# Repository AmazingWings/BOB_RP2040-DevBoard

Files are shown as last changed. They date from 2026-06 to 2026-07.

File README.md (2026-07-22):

<div align="center">

# BOB
### A Raspberry Pi RP2040 development board




### [Key Features](#key-features) • [PCB](#pcb) • [Credits](#credits) • [License](#license)

</div>

---

## Welcome!
Hi! This is my first SMT board! It is a custom RP2040 development board named BOB. I chose BOB as the name because I like Bob; it's a fun name to say. But on the other hand, it is designed to act as a platform for me to learn SMT board design. The reason why I made it was not only to learn how to make a fully SMT board, but to serve as a platform for learning for my future flight computer designs I will do for my rockets. I wanted to transition away from using software like EasyEDA to more professional software like KiCad, which is much more widely used. Through this project, I not only learned SMT schematic design but also routing. In EasyEDA, I used to autoroute my components, but in KiCad and through this project, I learned how to route components and place components by myself, transitioning away from my dependencies with breakout boards. 

### Key features:
1. Dual-core processor with up to 133 MHz in speed.
2. 264 KB of on-chip SRAM.
3. Programmable through USB-C.
4. 30 GPIO pins that can run I2C, SPI, and UART. 
5. 2-layer PCB design: top layer for components and bottom layer for ground wiring and signal routing, along with the top layer for signal wiring and power wiring.

---

## PCB

### Schematic Design 
<p align="center">
  Schematic Design
</p>

### PCB Design
<p align="center">
  PCB Design
</p>

### 3D Design
<p align="center">
  3D Design
</p>

### JLC PCB 3D Design
<p align="center">
  JLC PCB 3D Design
</p>

### BOM
<p <p align="center">
  Screenshot 2026-07-22 at 1 04 08 PM
</p>

### Final Cost Estimate
<p align="center">
  Final Cost Estimate
</p>

---

## Credits
1. https://macondo.hackclub.com/docs/build-a-devboard
2. [KiCad](https://www.kicad.org/) 
3. [JLCPCB](https://jlcpcb.com/)

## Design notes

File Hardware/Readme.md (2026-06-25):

<div align="center">

# Production Files
### RP2040 BOB Devboard
</div>

---

This folder contains all the necessary production files required to manufacture the **RP2040 BOB devboard**. 

---

## 🛠️ How to Use (Manufacturing)

If you want to order this board, simply **drag and drop the entire folder into JLCPCB**. Their system will automatically detect and compile all the necessary files you need for production.

## 📄 Key Files

* **BOM (Bill of Materials):** Provided in standard `.csv` format, ready for component sourcing and assembly.

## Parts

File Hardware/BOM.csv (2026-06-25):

RP2040_dev
Id | Designator | Footprint | Quantity | Comment | Supplier and ref
1 | 33pF2, 33pF3 | C_0402_1005Metric | 2 | 33pF
2 | C1, C2, C3, C4, C5, C6, C7, C8, C9, C11, C12, C15 | C_0402_1005Metric | 12 | 0.1uF
3 | C10 | C_0402_1005Metric | 1 | 1uF
4 | C13, C14 | C_0603_1608Metric | 2 | 10uF
5 | J1 | USB_C_Receptacle_HRO_TYPE-C-31-M-12 | 1 | USB_C_Receptacle_USB2.0_14P
6 | J2, J4 | PinHeader_1x20_P2.54mm_Vertical | 2 | Conn_01x20
7 | J3 | PinHeader_1x03_P2.54mm_Vertical | 1 | Conn_01x03
8 | R1, R2 | R_0402_1005Metric | 2 | 5.1K
9 | R3, R4 | R_0402_1005Metric | 2 | 27
10 | R5, R6 | R_0402_1005Metric | 2 | 1K
11 | R7 | R_0402_1005Metric | 1 | 10K
12 | SW1 | SW_Push_SPST_NO_Alps_SKRK | 1 | SW_Push
13 | U1 | QFN-56-1EP_7x7mm_P0.4mm_EP3.2x3.2mm | 1 | RP2040
14 | U2 | SOT-23 | 1 | MCP1700x-330xxTT
15 | U4 | Winbond_USON-8-1EP_3x2mm_P0.5mm_EP0.2x1.6mm | 1 | W25Q16JVSS
16 | Y1 | Crystal_SMD_3225-4Pin_3.2x2.5mm | 1 | 12mhz

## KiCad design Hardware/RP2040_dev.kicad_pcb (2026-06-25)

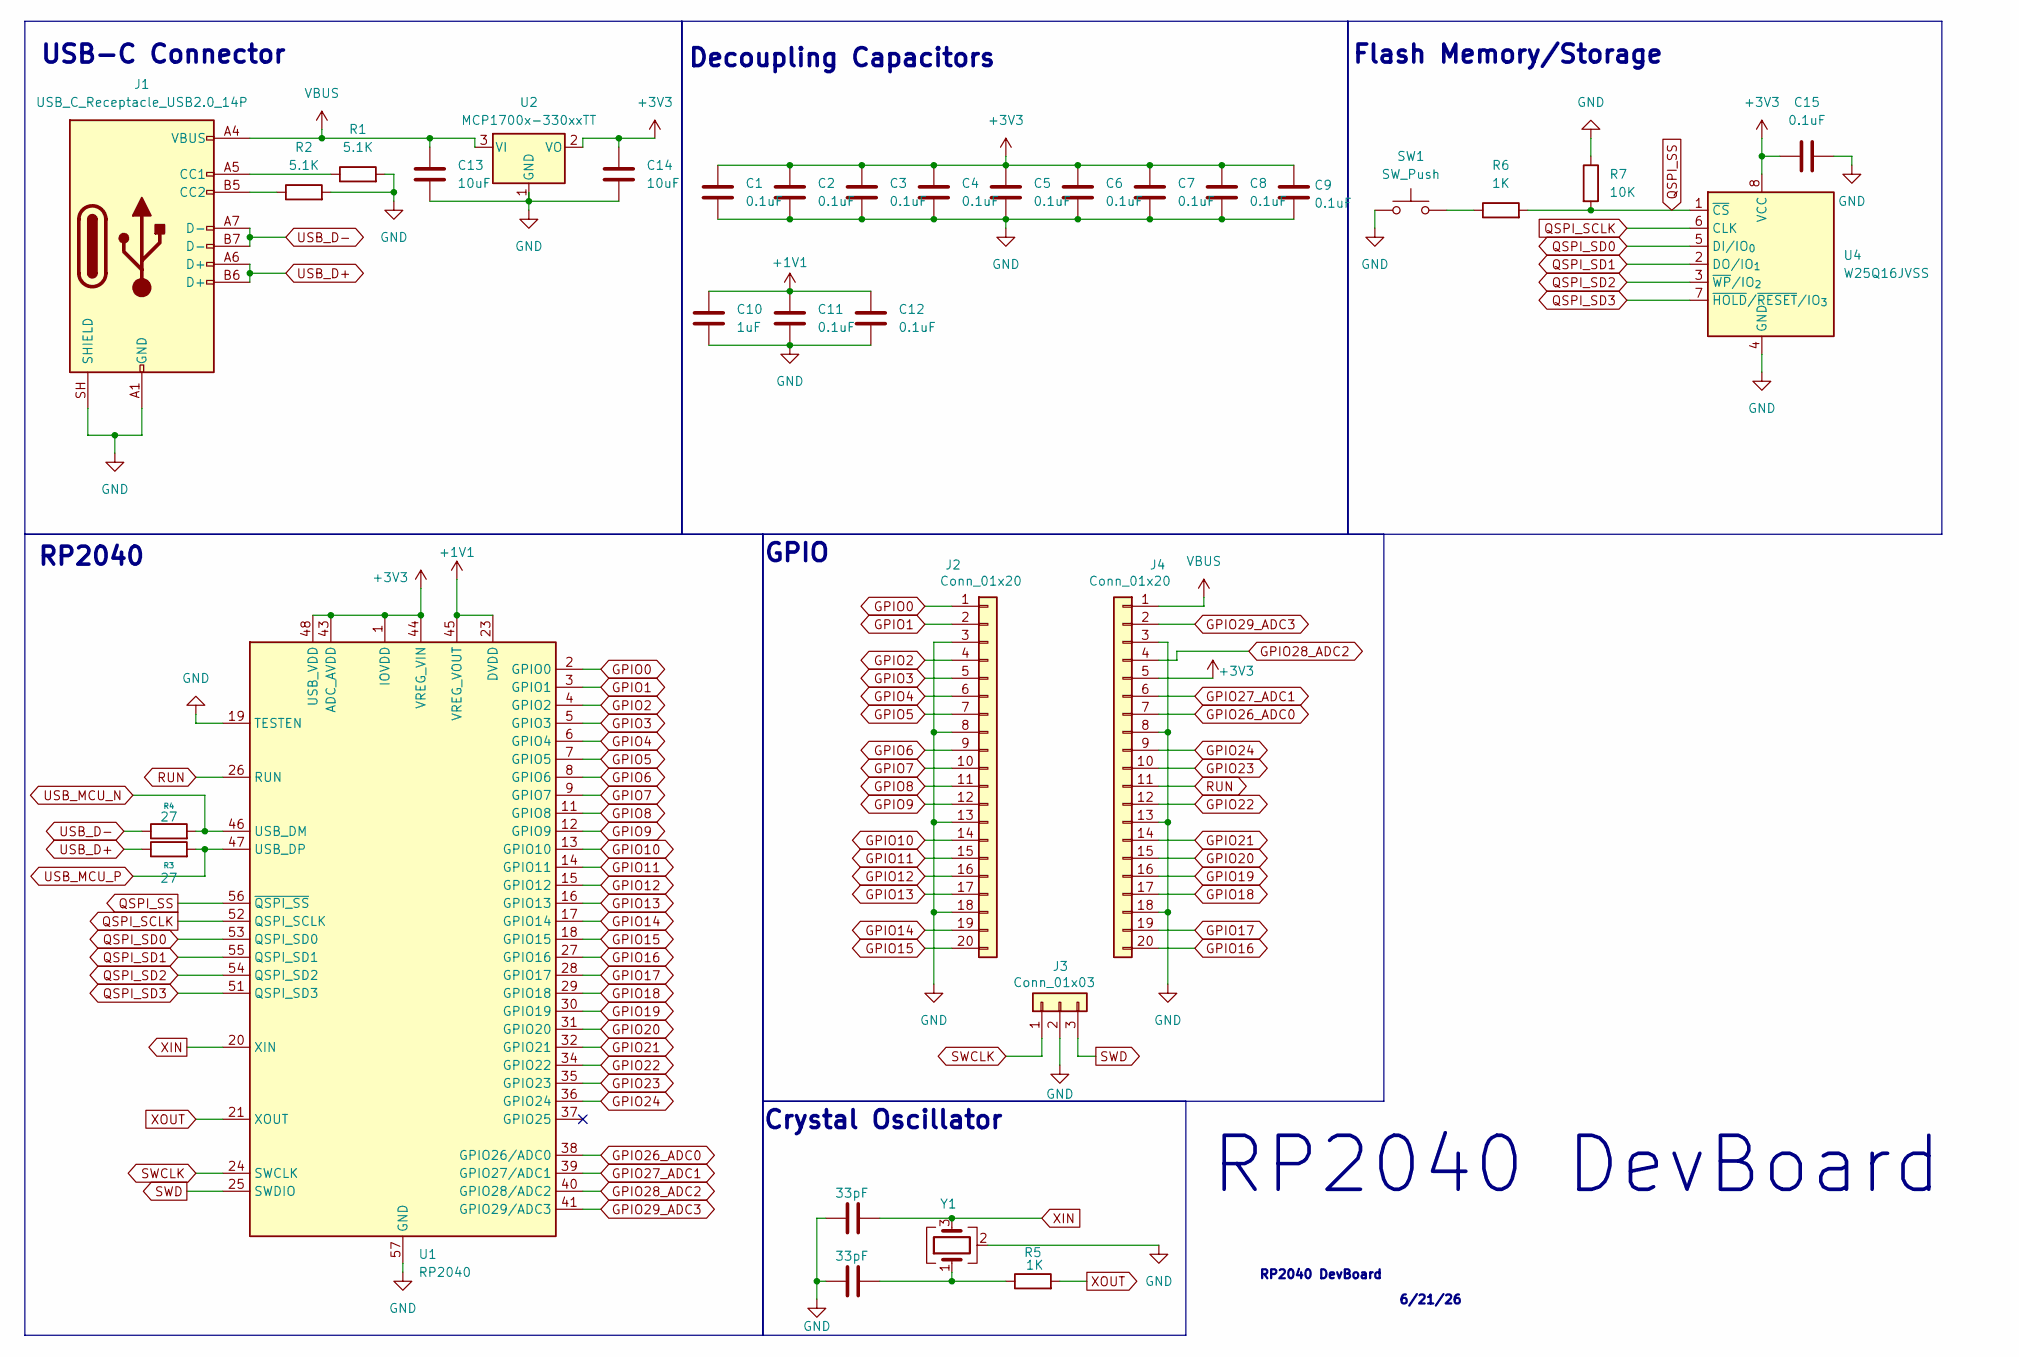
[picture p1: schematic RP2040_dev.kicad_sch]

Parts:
33pF2, 33pF3: 33pF; C_0402_1005Metric
C1, C2, C3, C4, C5, C6, C7, C8, C9, C11, C12, C15: 0.1uF; C_0402_1005Metric
C10: 1uF; C_0402_1005Metric
C13, C14: 10uF; C_0603_1608Metric
J1: USB_C_Receptacle_USB2.0_14P; USB_C_Receptacle_HRO_TYPE-C-31-M-12
J2, J4: Conn_01x20; PinHeader_1x20_P2.54mm_Vertical
J3: Conn_01x03; PinHeader_1x03_P2.54mm_Vertical
R1, R2: 5.1K; R_0402_1005Metric
R3, R4: 27; R_0402_1005Metric
R5, R6: 1K; R_0402_1005Metric
R7: 10K; R_0402_1005Metric
SW1: SW_Push; SW_Push_SPST_NO_Alps_SKRK
U1: RP2040; QFN-56-1EP_7x7mm_P0.4mm_EP3.2x3.2mm
U2: MCP1700x-330xxTT; SOT-23
U4: W25Q16JVSS; Winbond_USON-8-1EP_3x2mm_P0.5mm_EP0.2x1.6mm
Y1: 12mhz; Crystal_SMD_3225-4Pin_3.2x2.5mm

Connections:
+1V1: C10.1, C11.1, C12.1, U1.23 (DVDD), U1.45 (VREG_VOUT), U1.50 (DVDD)
+3V3: C1.1, C2.1, C3.1, C4.1, C5.1, C6.1, C7.1, C8.1, C9.1, C14.1, C15.1, J4.5, U1.1 (IOVDD), U1.10 (IOVDD), U1.22 (IOVDD), U1.33 (IOVDD), U1.42 (IOVDD), U1.43 (ADC_AVDD), U1.44 (VREG_VIN), U1.48 (USB_VDD), U1.49 (IOVDD), U2.2 (VO), U4.8 (VCC)
GND: 33pF2.1, 33pF3.1, C1.2, C2.2, C3.2, C4.2, C5.2, C6.2, C7.2, C8.2, C9.2, C10.2, C11.2, C12.2, C13.2, C14.2, C15.2, J1.A1 (GND), J1.A12 (GND), J1.B1 (GND), J1.B12 (GND), J1.SH (SHIELD), J2.3, J2.8, J2.13, J2.18, J3.2, J4.3, J4.8, J4.13, J4.18, R1.2, R2.2, R7.1, SW1.1, U1.19 (TESTEN), U1.57 (GND), U2.1 (GND), U4.4 (GND), Y1.2 (G), Y1.4 (G)
GPIO0: J2.1, U1.2 (GPIO0)
GPIO1: J2.2, U1.3 (GPIO1)
GPIO2: J2.4, U1.4 (GPIO2)
GPIO3: J2.5, U1.5 (GPIO3)
GPIO4: J2.6, U1.6 (GPIO4)
GPIO5: J2.7, U1.7 (GPIO5)
GPIO6: J2.9, U1.8 (GPIO6)
GPIO7: J2.10, U1.9 (GPIO7)
GPIO8: J2.11, U1.11 (GPIO8)
GPIO9: J2.12, U1.12 (GPIO9)
GPIO10: J2.14, U1.13 (GPIO10)
GPIO11: J2.15, U1.14 (GPIO11)
GPIO12: J2.16, U1.15 (GPIO12)
GPIO13: J2.17, U1.16 (GPIO13)
GPIO14: J2.19, U1.17 (GPIO14)
GPIO15: J2.20, U1.18 (GPIO15)
GPIO16: J4.20, U1.27 (GPIO16)
GPIO17: J4.19, U1.28 (GPIO17)
GPIO18: J4.17, U1.29 (GPIO18)
GPIO19: J4.16, U1.30 (GPIO19)
GPIO20: J4.15, U1.31 (GPIO20)
GPIO21: J4.14, U1.32 (GPIO21)
GPIO22: J4.12, U1.34 (GPIO22)
GPIO23: J4.10, U1.35 (GPIO23)
GPIO24: J4.9, U1.36 (GPIO24)
GPIO26_ADC0: J4.7, U1.38 (GPIO26/ADC0)
GPIO27_ADC1: J4.6, U1.39 (GPIO27/ADC1)
GPIO28_ADC2: J4.4, U1.40 (GPIO28/ADC2)
GPIO29_ADC3: J4.2, U1.41 (GPIO29/ADC3)
unnamed: 33pF2.2, R5.1, Y1.1
unnamed: J1.A5 (CC1), R1.1
unnamed: J1.B5 (CC2), R2.1
unnamed: R6.1, SW1.2
QSPI_SCLK: U1.52 (QSPI_SCLK), U4.6 (CLK)
QSPI_SD0: U1.53 (QSPI_SD0), U4.5 (DI/IO_{0})
QSPI_SD1: U1.55 (QSPI_SD1), U4.2 (DO/IO_{1})
QSPI_SD2: U1.54 (QSPI_SD2), U4.3 (~WP/IO_{2})
QSPI_SD3: U1.51 (QSPI_SD3), U4.7 (~HOLD/~RESET/IO_{3})
QSPI_SS: R6.2, R7.2, U1.56 (~QSPI_SS), U4.1 (~CS)
RUN: J4.11, U1.26 (RUN)
SWCLK: J3.1, U1.24 (SWCLK)
SWD: J3.3, U1.25 (SWDIO)
USB_D+: J1.A6 (D+), J1.B6 (D+), R3.1
USB_D-: J1.A7 (D-), J1.B7 (D-), R4.1
USB_MCU_N: R4.2, U1.46 (USB_DM)
USB_MCU_P: R3.2, U1.47 (USB_DP)
VBUS: C13.1, J1.A4 (VBUS), J1.A9 (VBUS), J1.B4 (VBUS), J1.B9 (VBUS), J4.1, U2.3 (VI)
XIN: 33pF3.2, U1.20 (XIN), Y1.3
XOUT: R5.2, U1.21 (XOUT)

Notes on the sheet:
RP2040
USB-C Connector
Flash Memory/Storage
Crystal Oscillator
GPIO
RP2040 DevBoard
Decoupling Capacitors
6/21/26

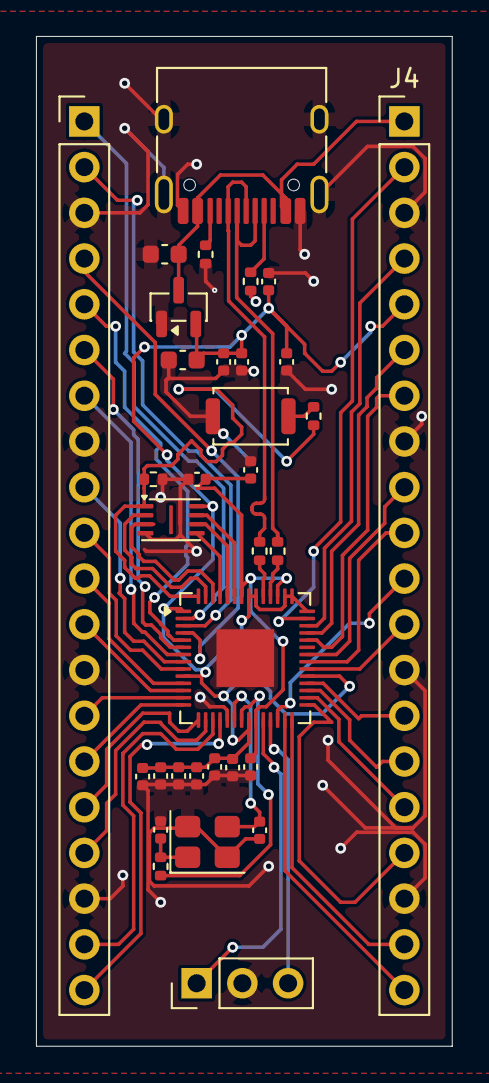
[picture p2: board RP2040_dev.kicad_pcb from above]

Board: 2 copper layers, 23.1 x 56.1 mm, 33 parts (0 on the bottom side), 52 nets.

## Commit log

2026-07-22 Create Gerber
2026-07-22 Add BOM section to README
    Added BOM section with an image to the README.
2026-07-22 Center align BOM image in README
    Updated BOM section to center align the image.
